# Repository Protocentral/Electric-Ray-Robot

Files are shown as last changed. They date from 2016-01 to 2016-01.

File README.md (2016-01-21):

Electric Ray Robot
======================

[Electric Ray Robot  *Electric Ray Arduino-compatible robot (PC-0213)*](https://www.protocentral.com/robotics-kits/475-electric-ray-robot.html?search_query=electric+ray&results=3)

Electric Ray is a Ardino-Uno compatible, entry-level, low-cost complete robotic platform. It is simple enough to be used out-of-the-box for teaching and learning about robotics, electronics and Arduino programming. At the same time, it also allows one to add any number unlimited functions with the help of Arduino-compatible shields.

Specifications
---------------
* Atmega328 microcontroller with Optiboot bootloader (Arduino-Uno compatible)
* Arduino shield expansion headers
* Ultrasonic distance sensor
* 3x IR sensors
* OLED display
* Piezo buzzer
* FTDI USB-to-serial coverter
* TB6612FNG Motor Driver
* 2x 3V geared motors
* 2x wheels with rubber tyres
* 1100 mAH, 3.7V Li-Poly battery pack
* Clear acrylic sheet to cover the PCB

Repository Contents
-------------------
* **/Libraries** - Arduino library and example sketches.
* **/Hardware** - All Eagle design files (.brd, .sch)
* **/extras** - includes the datasheet

License Information
-------------------
This product is open source!

Please use, reuse, and modify these files as you see fit. Please maintain attribution to Protocentral and release anything derivative under the same license.

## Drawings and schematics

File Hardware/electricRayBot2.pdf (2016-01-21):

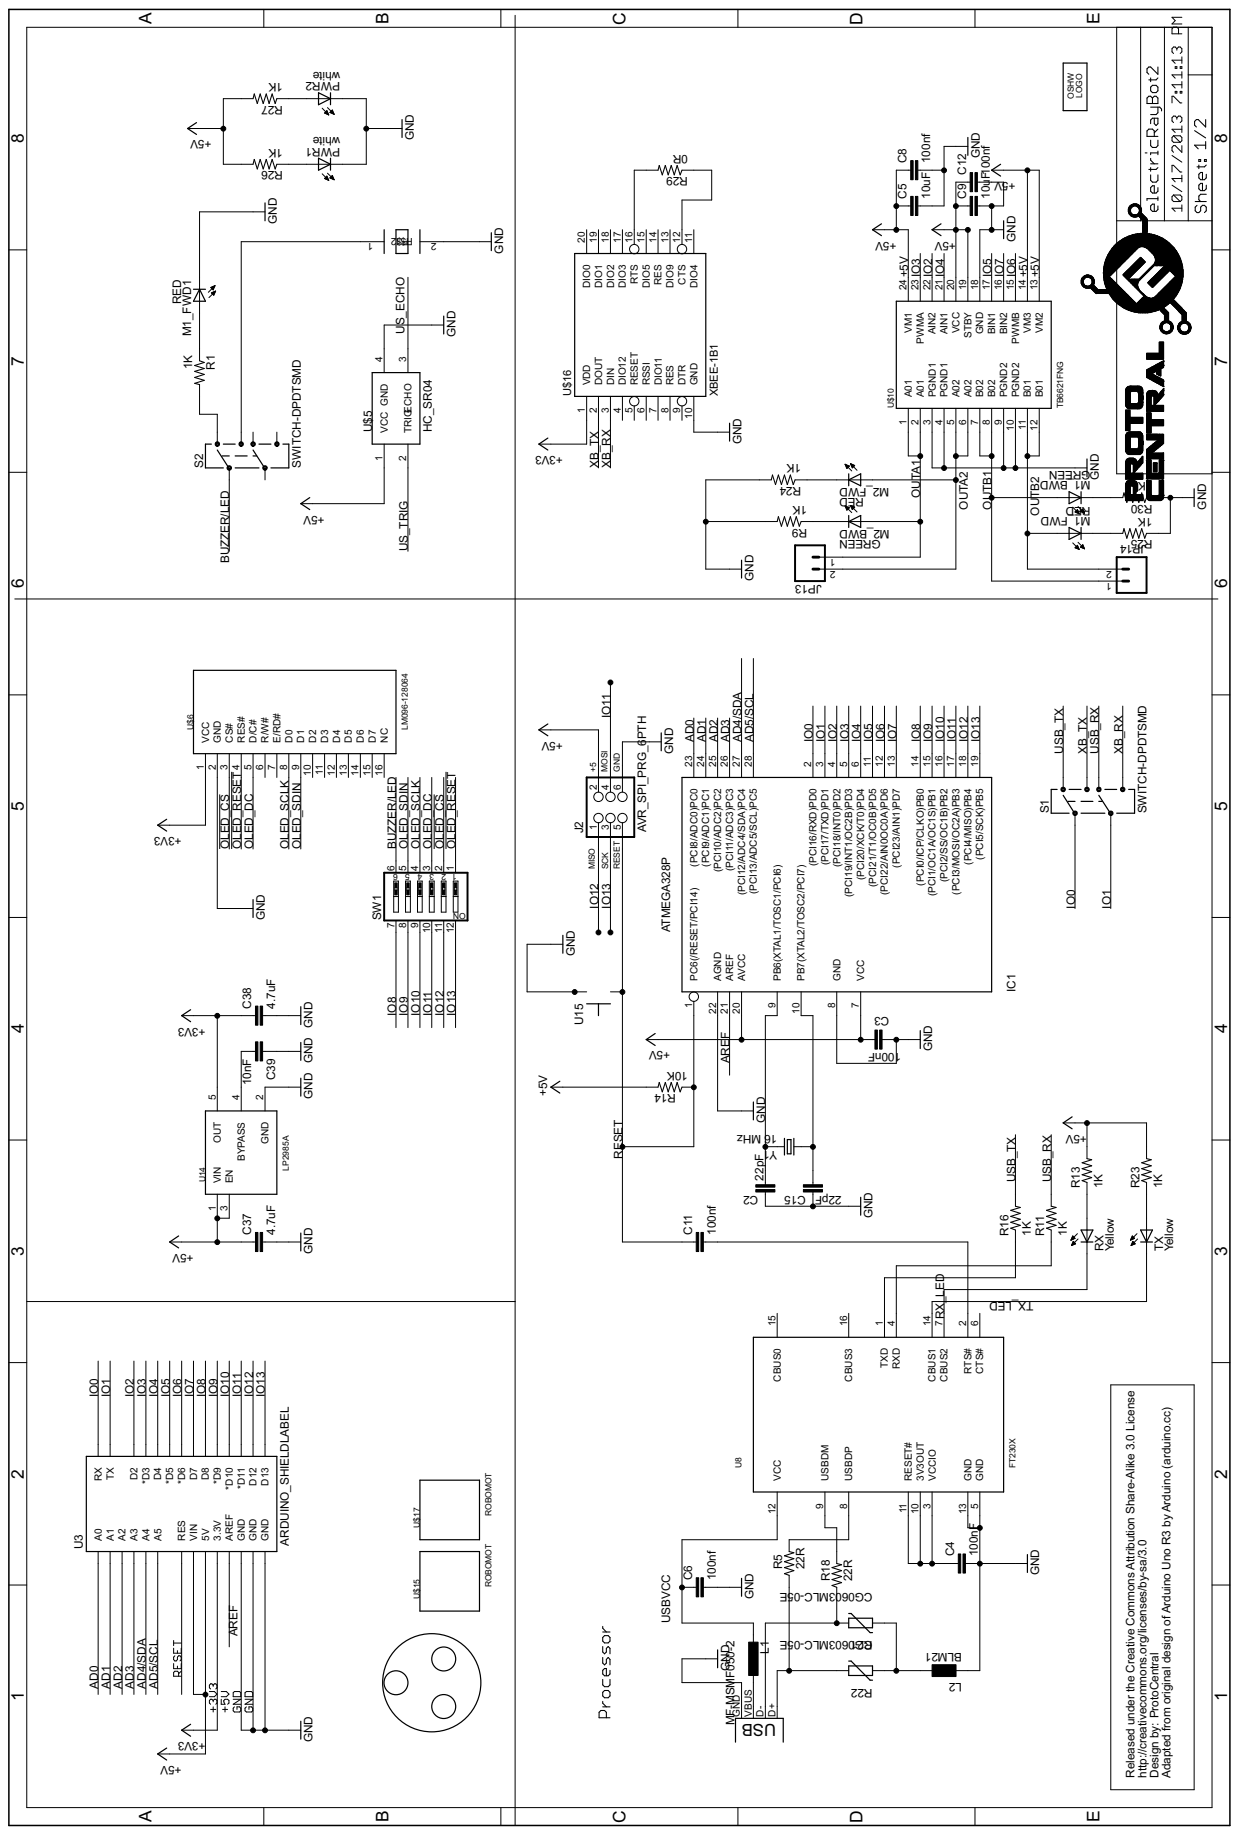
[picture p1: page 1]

MOSI RESET SCK MISO +5GND

Released under the Creative Commons Attribution Share-Alike 3.0 License

ProtoCentral Adapted from original design of Arduino Uno R3 by Arduino (arduino.cc)

AREF GND GND GND

http:/ creativecommons.org/licenses/by-sa/3.0 Design by:

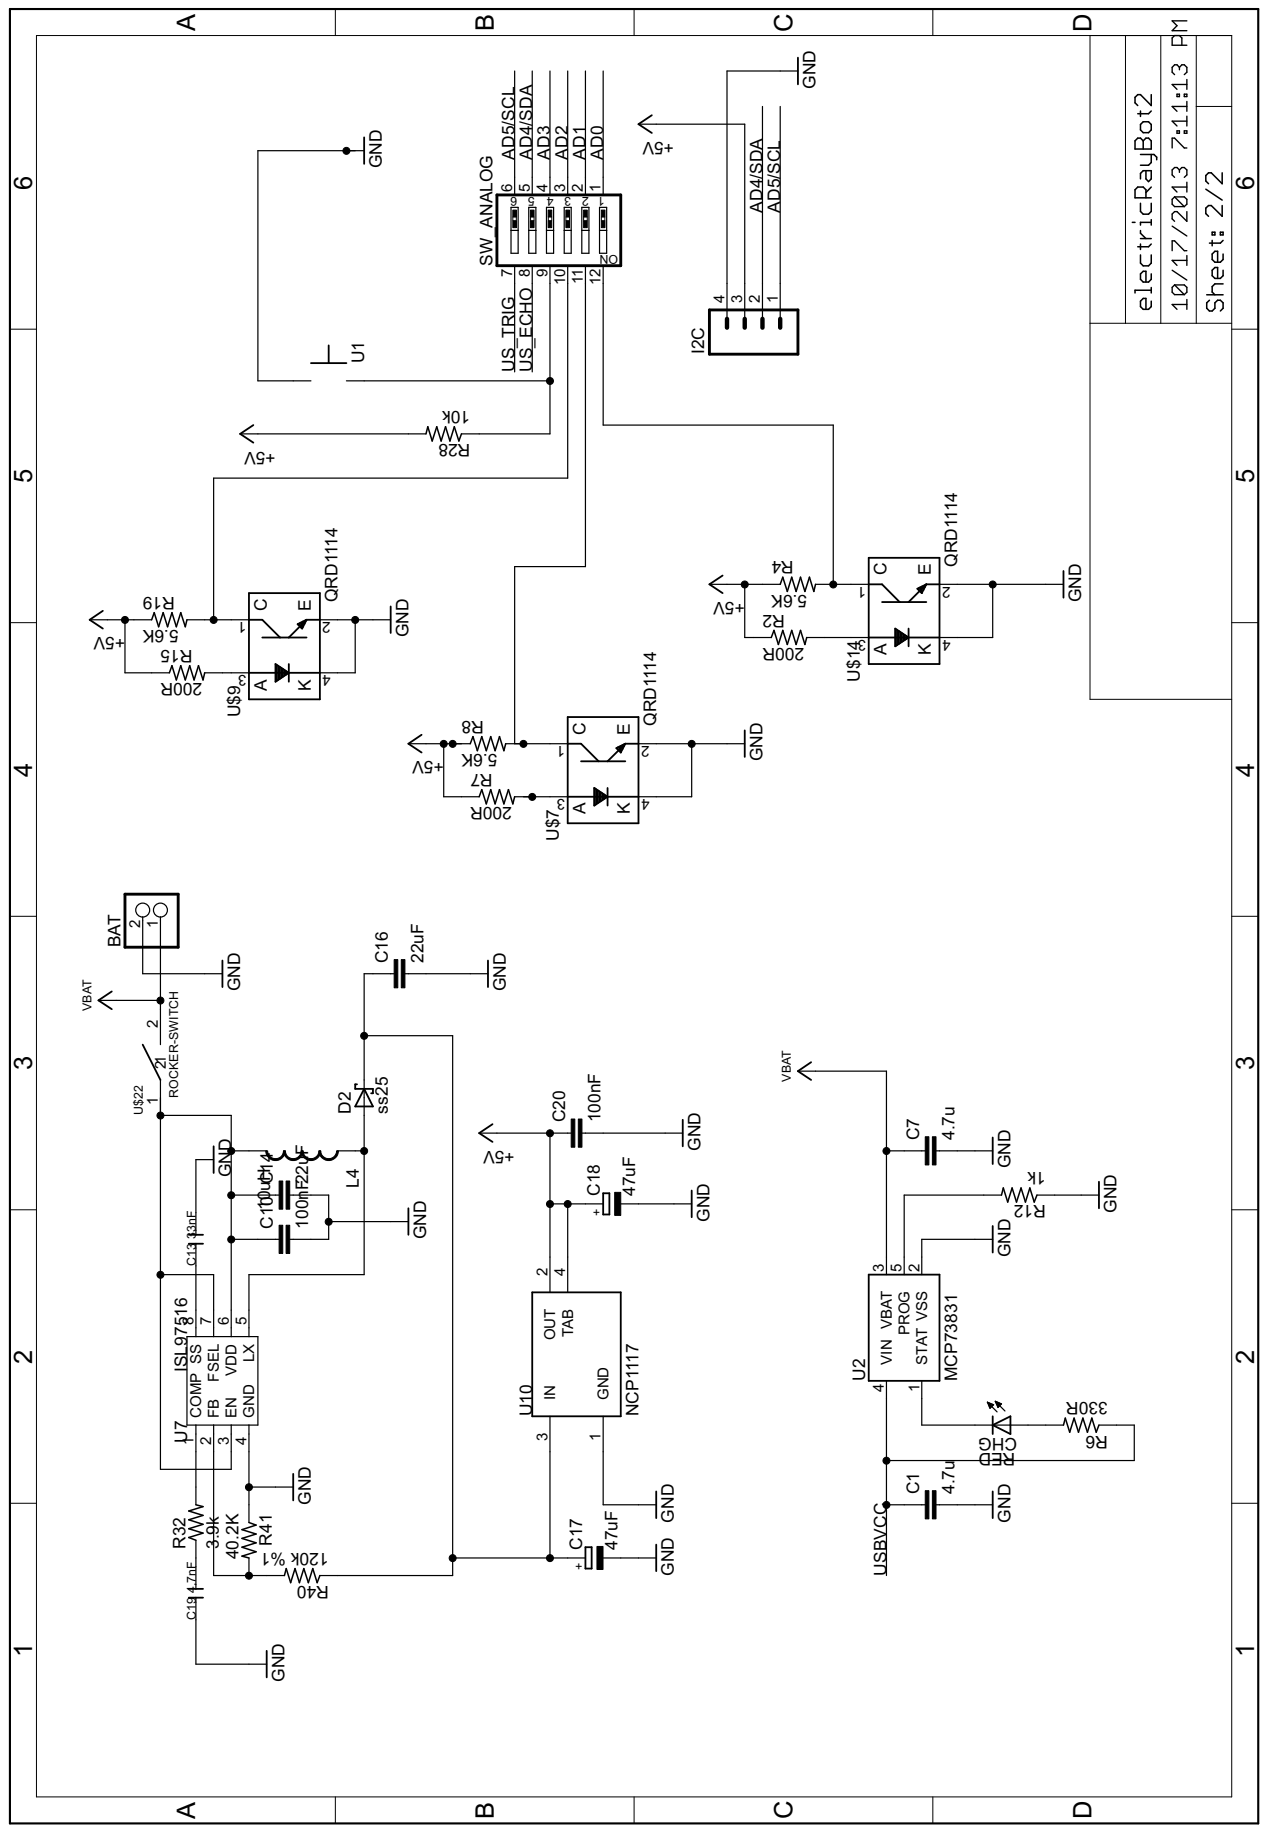
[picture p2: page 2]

QRD1114 QRD1114 QRD1114 GNDGND V5+ V5+ V5+ GND GND GND V5+ MCP73831 4.7u 4.7u GND DER R033 GND GND k1 GND VBAT k01 V5+ ISL97516 33nF 3.9k 4.7nF 1 %k021 40.2K 10uH GND GND GND 100nF22uF GND 22uF GND ss25 GND VBAT NCP1117 GND 47uF 47uF GND 100nF GND GND V5+ R002 K6. 5 R002 K6. 5 R002 K6. 5 U$7 1 2 3 4 U$9 1 2 3 4 U$14 1 2 3 4 U1 SW_ANALOG 789101112 654321 I2C 4321 U2VIN 4 STAT 1 VBAT 3 PROG 5 VSS 2 C1 C7 GHC 6R 21R 82R U7 COMP 1 FB 2 EN 3 GND 4 LX 5 VDD 6 FSEL 7 SS 8 C13 R32 C19 04R R41 L4 C10 C14 C16 D2 BAT21 U10IN 3 GND 1 OUT 2 TAB 4 C17 C18 C20 2R4R 7R 8R 51R 91R1 1 2 2 U$22ROCKER-SWITCH AD0 AD1 AD2 AD3 AD4/SDA AD4/SDAAD5/SCL AD5/SCL USBVCC US_ECHO US_TRIG ABCD 1 2 3 4 5 6 ABCD 1 2 3 4 5 6 AK CE AK CE AK CE 6 5 4 3 2 1NO + +

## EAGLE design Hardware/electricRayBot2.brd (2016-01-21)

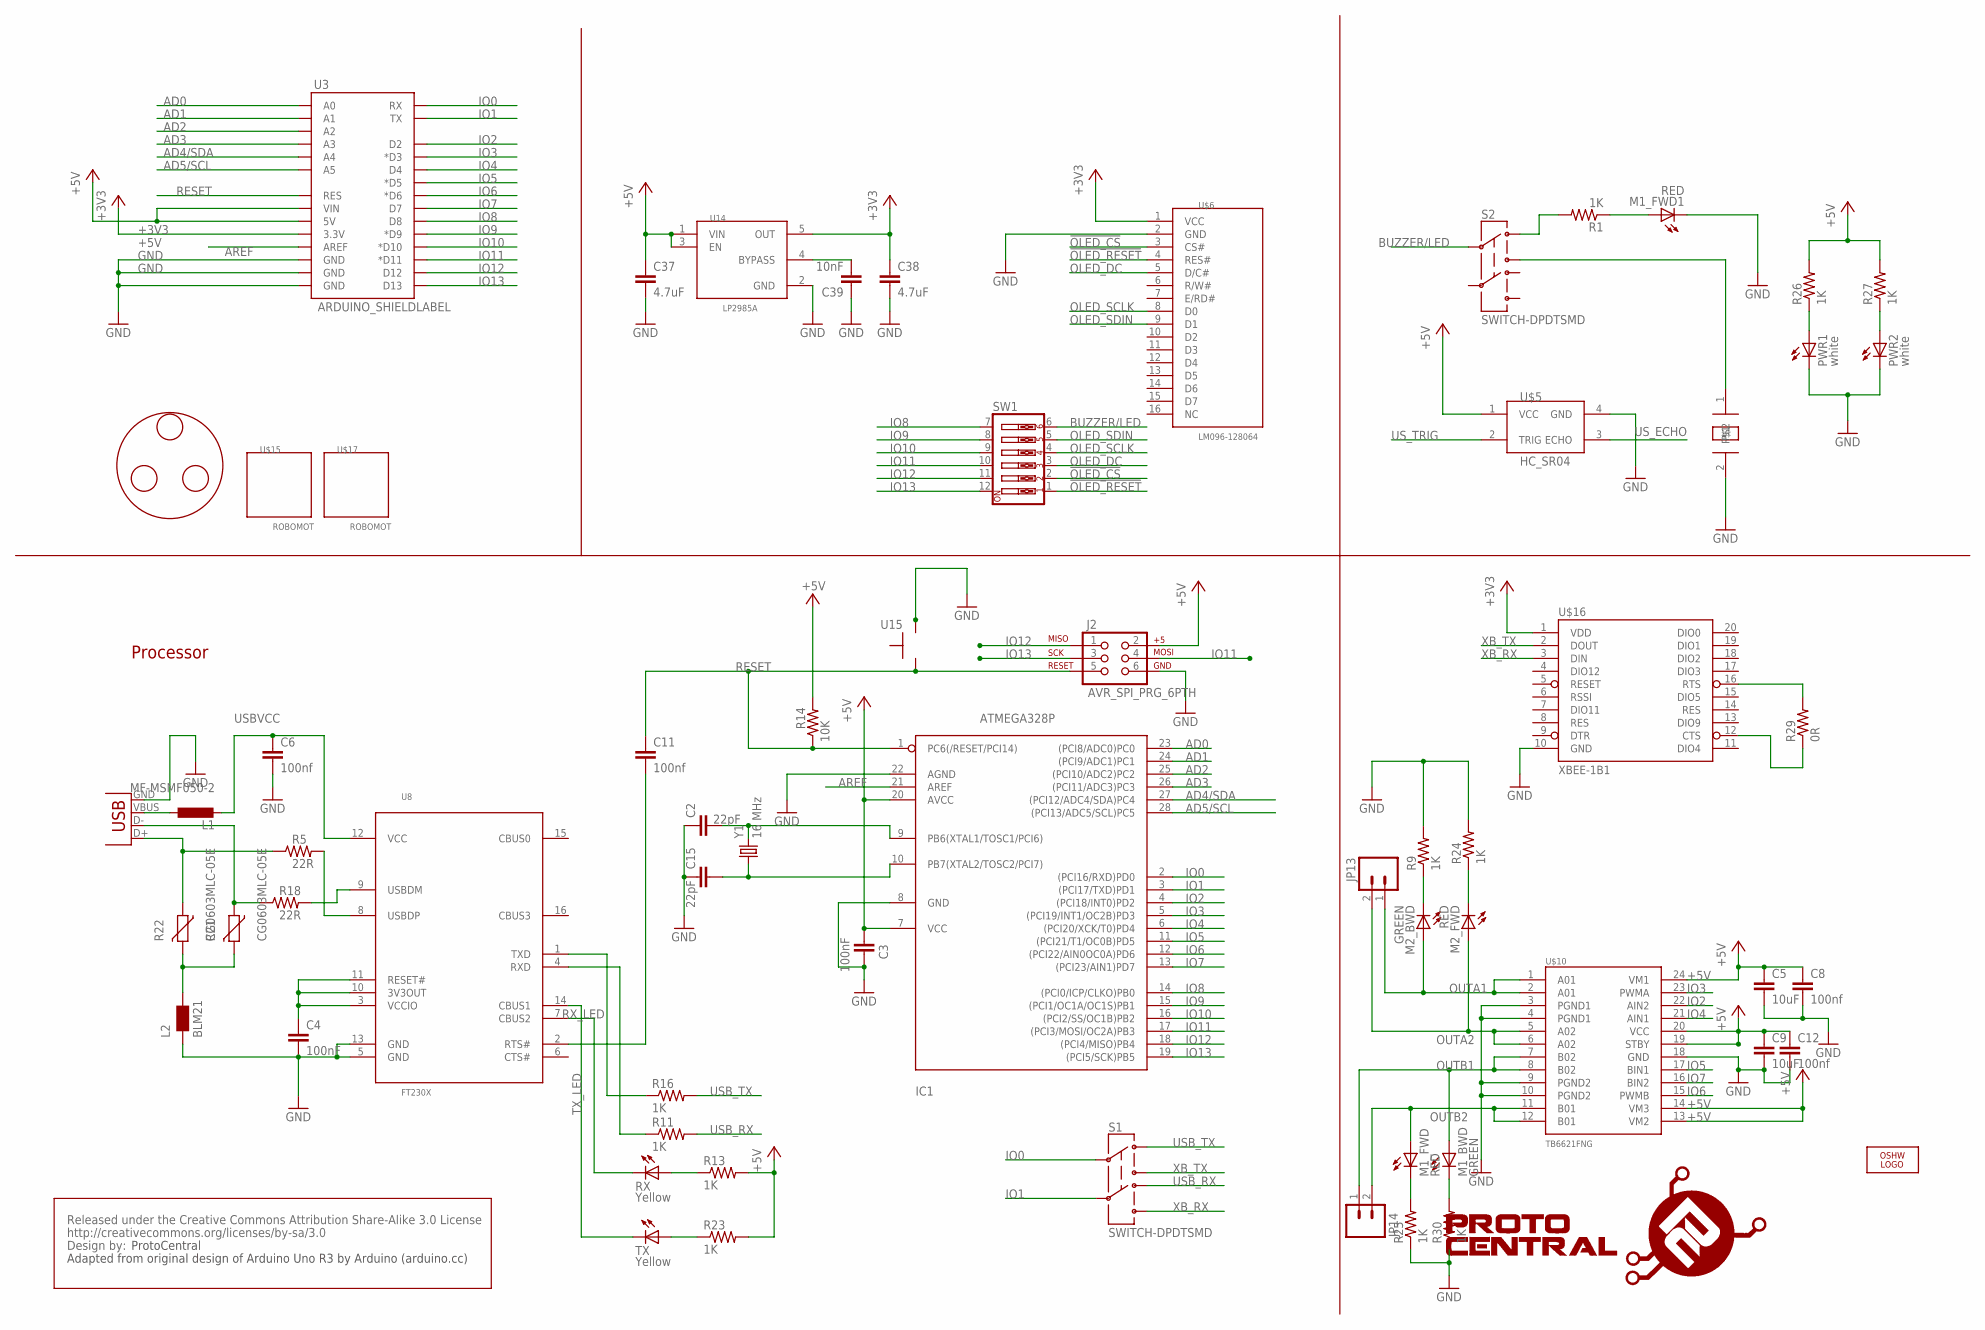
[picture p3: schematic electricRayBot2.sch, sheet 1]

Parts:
C2, C15: 22pF; C0402
C3, C4: 100nF; C0805
C5, C9: 10uF; C0805
C6, C8, C11, C12: 100nf; C0805
C37, C38: 4.7uF; C0805
C39: 10nF; C0805
IC1: ATMEGA328P; DIP28
J2: AVR_SPI_PRG_6PTH; 2X3
JP13, JP14: M023.5MM; SCREWTERMINAL-3.5MM-2
L1: MF-MSMF050-2; L1812
L2: BLM21; 0805
LOGO2: OSHW_LOGO_FILLX0350-NT; OSHW_FILLX350_NOTEXT
M1_BWD, M2_BWD: GREEN; CHIPLED_0603
M1_FWD, M1_FWD1, M2_FWD: RED; CHIPLED_0603
PWR1, PWR2: white; LED-0603
R1, R9, R11, R13, R16, R23, R24, R25, R26, R27, R30: 1K; R0805
R5, R18: 22R; R0805
R14: 10K; R0805
R21, R22: CG0603MLC-05E; CT/CN0603
R29: 0R; R0805
RX: Yellow; CHIPLED_0603
S1, S2: SWITCH-DPDTSMD; AYZ0202
SW1: SW_DIP-6; EDG-06
TX: Yellow; CHIPLED_0603
U3: ARDUINO_SHIELDLABEL; DUEMILANOVE_SHIELD
U8: FT230X; SSOP_16
U14: LP2985A; SOT23-5
U15: EVQQ2
U$1: CREATIVE_COMMONS
U$4: PS1740; PS02
U$5: HC_SR04; ULTRA
U$6: LM096-128064; LM096-128064(OLED)
U$10: TB6621FNG; SSOP24
U$15, U$17: ROBOMOT
U$16: XBEE-1B1; XBEE-1
U$18: PROTY-LOGO; LOGO-PROTY
U$20: MOTO
X1: USBPTH; USB-B-PTH
Y1: 16 MHz; HC49US

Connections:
!OLED_CS: SW1.2, U$6.3 (CS#)
!OLED_RESET: SW1.1, U$6.4 (RES#)
+3V3: C38.1, U3.3.3V, U14.5 (OUT), U$6.1 (VCC), U$16.1 (VDD)
+5V: C3.1, C5.1, C8.1, C9.1, C12.1, C37.1, IC1.7 (VCC), IC1.20 (AVCC), J2.2, R13.2, R14.2, R23.2, R26.2, R27.2, U3.5V, U3.VIN, U14.1 (VIN), U14.3 (EN), U$5.1 (VCC), U$10.13 (VM2), U$10.14 (VM3), U$10.19 (STBY), U$10.20 (VCC), U$10.24 (VM1); also elsewhere on the board
AD0: IC1.23 ((PCI8/ADC0)PC0), U3.A0; also elsewhere on the board
AD1: IC1.24 ((PCI9/ADC1)PC1), U3.A1; also elsewhere on the board
AD2: IC1.25 ((PCI10/ADC2)PC2), U3.A2; also elsewhere on the board
AD3: IC1.26 ((PCI11/ADC3)PC3), U3.A3; also elsewhere on the board
AD4/SDA: IC1.27 ((PCI12/ADC4/SDA)PC4), U3.A4; also elsewhere on the board
AD5/SCL: IC1.28 ((PCI13/ADC5/SCL)PC5), U3.A5; also elsewhere on the board
AREF: IC1.21 (AREF), U3.AREF
BUZZER: S2.3, U$4.1
BUZZER/LED: S2.2, SW1.6
GND: C2.1, C3.2, C4.2, C5.2, C6.2, C8.2, C9.2, C12.2, C15.1, C37.2, C38.2, C39.1, IC1.8 (GND), IC1.22 (AGND), J2.6, L2.1, M1_FWD1.C, PWR1.C, PWR2.C, R9.2, R24.2, R25.1, R30.1, U3.GND@0 (GND), U3.GND@1 (GND), U3.GND@2 (GND), U8.5 (GND), U8.13 (GND), U14.2 (GND), U15.P$3, U$4.2, U$5.4 (GND), U$6.2 (GND), U$10.3 (PGND1), U$10.4 (PGND1), U$10.9 (PGND2), U$10.10 (PGND2), U$10.18 (GND), U$16.10 (GND), X1.GND; also elsewhere on the board
IO0: IC1.2 ((PCI16/RXD)PD0), S1.2, U3.RX
IO1: IC1.3 ((PCI17/TXD)PD1), S1.5, U3.TX
IO2: IC1.4 ((PCI18/INT0)PD2), U3.D2, U$10.22 (AIN2)
IO3: IC1.5 ((PCI19/INT1/OC2B)PD3), U3.D3 (*D3), U$10.23 (PWMA)
IO4: IC1.6 ((PCI20/XCK/T0)PD4), U3.D4, U$10.21 (AIN1)
IO5: IC1.11 ((PCI21/T1/OC0B)PD5), U3.D5 (*D5), U$10.17 (BIN1)
IO6: IC1.12 ((PCI22/AIN0OC0A)PD6), U3.D6 (*D6), U$10.15 (PWMB)
IO7: IC1.13 ((PCI23/AIN1)PD7), U3.D7, U$10.16 (BIN2)
IO8: IC1.14 ((PCI0/ICP/CLKO)PB0), SW1.7, U3.D8
IO9: IC1.15 ((PCI1/OC1A/OC1S)PB1), SW1.8, U3.D9 (*D9)
IO10: IC1.16 ((PCI2/SS/OC1B)PB2), SW1.9, U3.D10 (*D10)
IO11: IC1.17 ((PCI3/MOSI/OC2A)PB3), J2.4, SW1.10, U3.D11 (*D11)
IO12: IC1.18 ((PCI4/MISO)PB4), J2.1, SW1.11, U3.D12
IO13: IC1.19 ((PCI5/SCK)PB5), J2.3, SW1.12, U3.D13
unnamed: PWR1.A, R26.1
unnamed: M1_FWD1.A, R1.1
unnamed: M2_BWD.C, R9.1
unnamed: PWR2.A, R27.1
unnamed: R18.2, U8.9 (USBDM)
unnamed: C4.1, U8.3 (VCCIO), U8.10 (3V3OUT), U8.11 (RESET#)
unnamed: R18.1, R21.1, X1.D-
unnamed: R5.2, U8.8 (USBDP)
unnamed: L1.1, X1.VBUS
unnamed: M1_FWD.C, R25.2
unnamed: M1_BWD.C, R30.2
unnamed: R29.2, U$16.16 (RTS)
unnamed: C39.2, U14.4 (BYPASS)
unnamed: R29.1, U$16.12 (CTS)
unnamed: M2_FWD.C, R24.1
unnamed: R1.2, S2.1
unnamed: R16.1, U8.1 (TXD)
unnamed: R11.1, U8.4 (RXD)
unnamed: R13.1, RX.A
unnamed: R23.1, TX.A
unnamed: C2.2, IC1.9 (PB6(XTAL1/TOSC1/PCI6)), Y1.2
unnamed: C15.2, IC1.10 (PB7(XTAL2/TOSC2/PCI7)), Y1.1
unnamed: C11.2, U8.2 (RTS#)
unnamed: L2.2, R21.2, R22.2
unnamed: R5.1, R22.1, X1.D+
OLED_DC: SW1.3, U$6.5 (D/C#)
OLED_SCLK: SW1.4, U$6.8 (D0)
OLED_SDIN: SW1.5, U$6.9 (D1)
OUTA1: JP13.1, M2_BWD.A, U$10.1 (A01), U$10.2 (A01)
OUTA2: JP13.2, M2_FWD.A, U$10.5 (A02), U$10.6 (A02)
OUTB1: JP14.1, M1_BWD.A, U$10.7 (B02), U$10.8 (B02)
OUTB2: JP14.2, M1_FWD.A, U$10.11 (B01), U$10.12 (B01)
RESET: C11.1, IC1.1 (PC6(/RESET/PCI14)), J2.5, R14.1, U3.RES, U15.P$1
RX_LED: RX.C, U8.7 (CBUS2)
TX_LED: TX.C, U8.14 (CBUS1)
USBVCC: C6.1, L1.2, U8.12 (VCC); also elsewhere on the board
USB_RX: R11.2, S1.4
USB_TX: R16.2, S1.1
US_ECHO: U$5.3 (ECHO); also elsewhere on the board
US_TRIG: U$5.2 (TRIG); also elsewhere on the board
XB_RX: S1.6, U$16.3 (DIN)
XB_TX: S1.3, U$16.2 (DOUT)

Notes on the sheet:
Processor
ProtoCentral
Adapted from original design of Arduino Uno R3 by Arduino (arduino.cc)

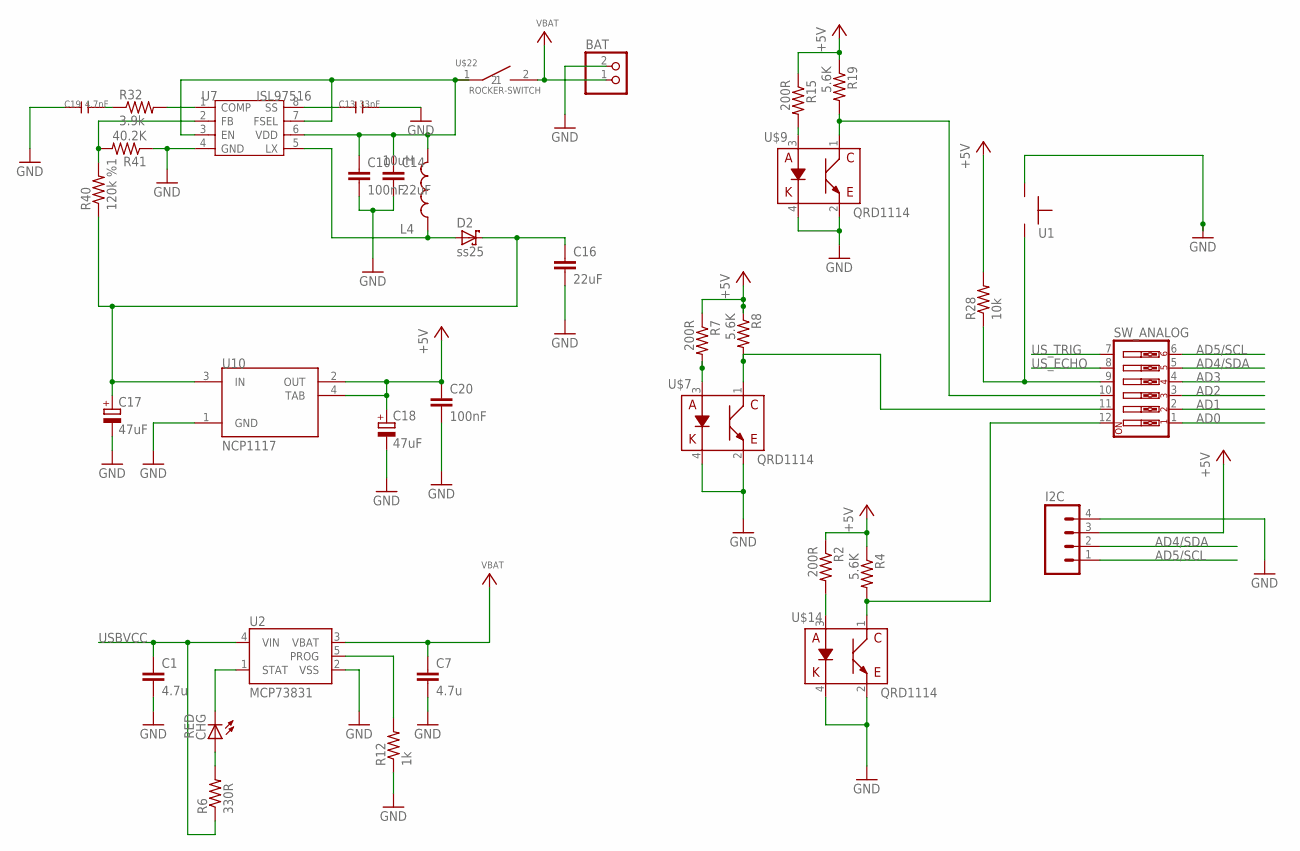
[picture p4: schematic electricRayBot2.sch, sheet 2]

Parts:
BAT: JST_2PIN-THM; JST-PH-2-THM
C1, C7: 4.7u; C0805
C10: 100nF; C0805
C13: 33nF; C0603
C14, C16: 22uF; C1206
C17, C18: 47uF; PANASONIC_D
C19: 4.7nF; C0603
C20: 100nF; C0402
CHG: RED; CHIPLED_0603
D2: ss25; SMB
I2C: M04POLAR_LOCK; MOLEX-1X4_LOCK
L4: 10uH; CDRH8D43
R2, R7, R15: 200R; R0805
R4, R8, R19: 5.6K; R0805
R6: 330R; R0805
R12: 1k; R0805
R28: 10k; R0805
R32: 3.9k; R0805
R40: 120k %1; R0805
R41: 40.2K; R0805
SW_ANALOG: SW_DIP-6; EDG-06
U1: EVQQ2
U2: MCP73831; SOT23-5
U7: ISL97516; MSOP8
U10: NCP1117; SOT223
U$7, U$9, U$14: QRD1114
U$22: ROCKER-SWITCH; SPST(RIGHT-ANGLE)

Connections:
+5V: C18.+, C20.1, I2C.3, R2.1, R4.1, R7.1, R8.1, R15.1, R19.1, R28.2, U10.2 (OUT), U10.4 (TAB); also elsewhere on the board
AD0: SW_ANALOG.1; also elsewhere on the board
AD1: SW_ANALOG.2; also elsewhere on the board
AD2: SW_ANALOG.3; also elsewhere on the board
AD3: SW_ANALOG.4; also elsewhere on the board
AD4/SDA: I2C.2, SW_ANALOG.5; also elsewhere on the board
AD5/SCL: I2C.1, SW_ANALOG.6; also elsewhere on the board
GND: BAT.2 (1), C1.2, C7.2, C10.2, C13.2, C14.2, C16.2, C17.-, C18.-, C19.1, C20.2, I2C.4, R12.1, R41.1, U1.P$1, U2.2 (VSS), U7.4 (GND), U10.1 (GND), U$7.2 (C), U$7.4 (K), U$9.2 (C), U$9.4 (K), U$14.2 (C), U$14.4 (K); also elsewhere on the board
IR1: R15.2, U$9.3 (A)
IR4: R7.2, U$7.3 (A)
IR5: R2.2, U$14.3 (A)
unnamed: CHG.C, U2.1 (STAT)
unnamed: CHG.A, R6.2
unnamed: R28.1, SW_ANALOG.9, U1.P$3
unnamed: C16.1, C17.+, D2.C, R40.1, U10.3 (IN)
unnamed: C13.1, U7.8 (SS)
unnamed: D2.A, L4.P$1 (1), U7.5 (LX)
unnamed: R12.2, U2.5 (PROG)
unnamed: R32.2, U7.1 (COMP)
unnamed: C19.2, R32.1
unnamed: R4.2, SW_ANALOG.12, U$14.1 (E)
unnamed: R8.2, SW_ANALOG.11, U$7.1 (E)
unnamed: R40.2, R41.2, U7.2 (FB)
unnamed: R19.2, SW_ANALOG.10, U$9.1 (E)
USBVCC: C1.1, R6.1, U2.4 (VIN); also elsewhere on the board
US_ECHO: SW_ANALOG.8; also elsewhere on the board
US_TRIG: SW_ANALOG.7; also elsewhere on the board
VBAT: BAT.1 (2), C7.1, U2.3 (VBAT), U$22.2
VDD: C10.1, C14.1, L4.P$2 (2), U7.3 (EN), U7.6 (VDD), U7.7 (FSEL), U$22.1

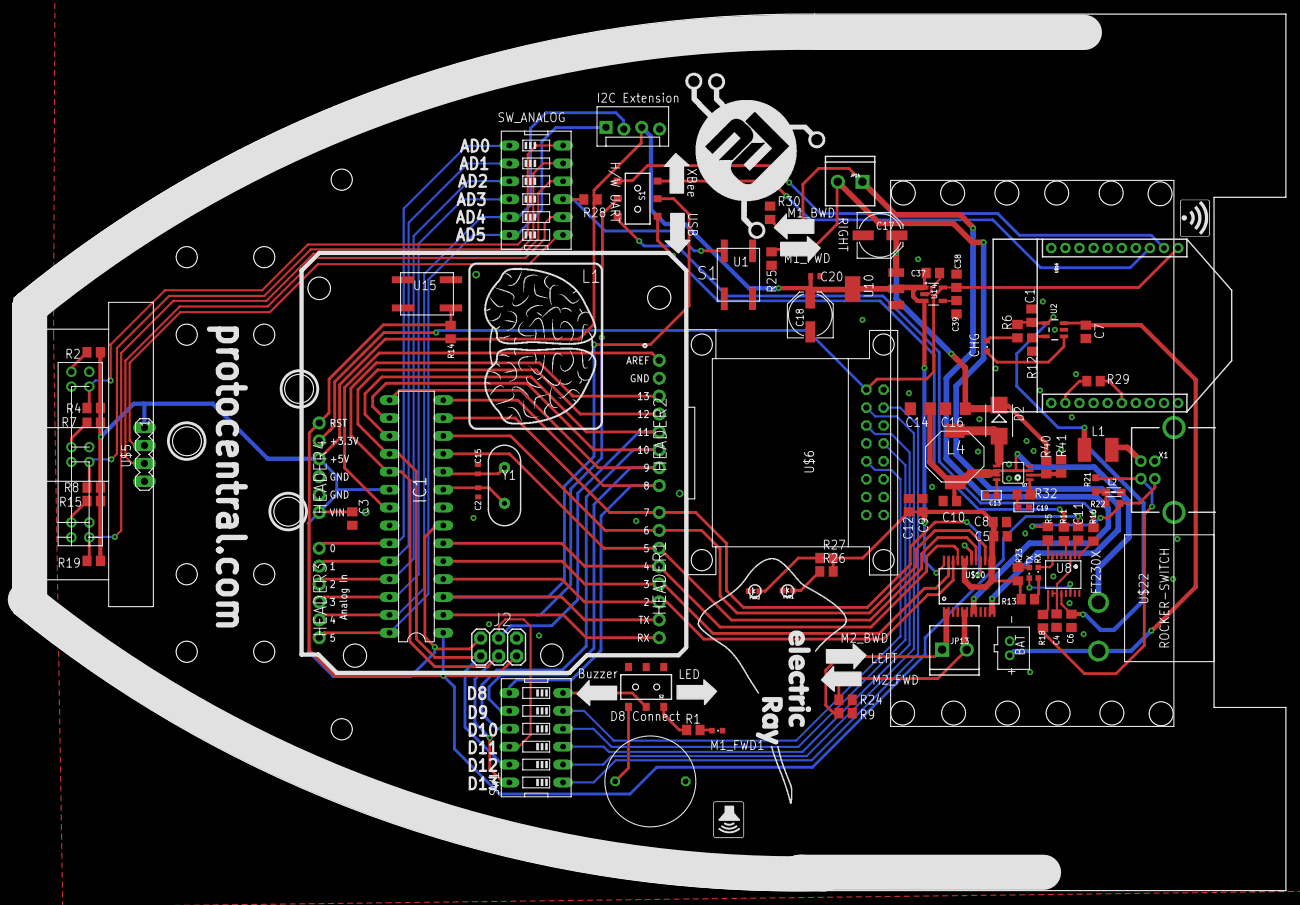
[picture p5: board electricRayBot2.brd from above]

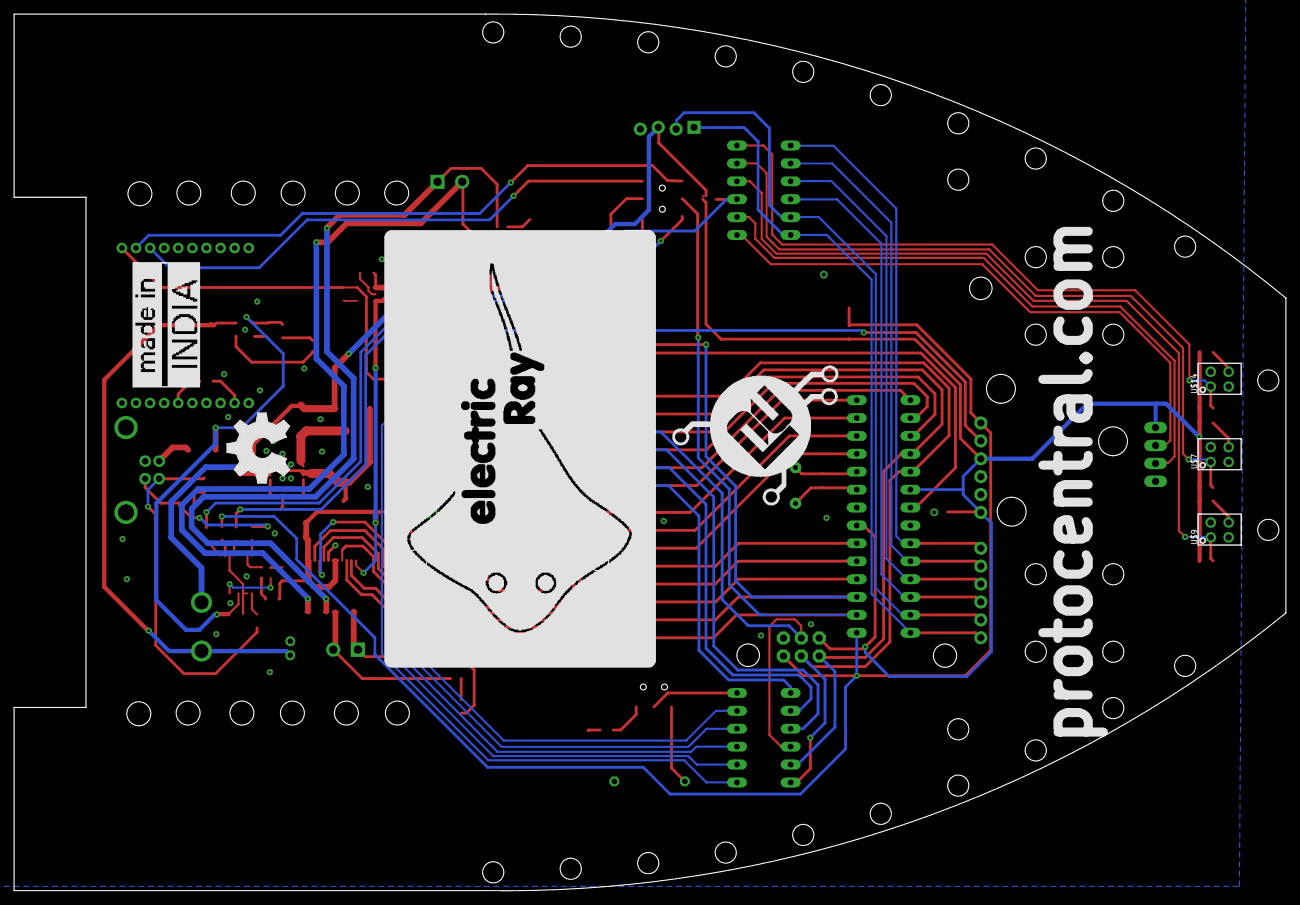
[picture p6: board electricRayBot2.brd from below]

Board: 4 copper layers, 180.5 x 124.4 mm, 109 parts (8 on the bottom side), 88 nets.

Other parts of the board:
U$2: MADEININDIA
U$3: BMP-SPEAKER
U$11: BMP-ELECTRICRAY
U$13, U$36: PROTY-LOGO-LARGE
U$19: BMP-WIRELESS
U$21: BMP-BRAIN
U$37: LOGO-ELECTRICRAY

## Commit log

2016-01-21 Design file
    [electricRayBot2.brd, electricRayBot2.sch]
2016-01-21 Arduino Sketch
